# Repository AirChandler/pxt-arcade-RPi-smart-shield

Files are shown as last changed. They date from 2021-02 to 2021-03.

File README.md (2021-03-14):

# MakeCode Arcade smart shield firmware

Firmware for shields with screen/buttons that enable MakeCode Arcade.
The shield drives the screen (in particular it can bit-bang a 320x240 parallel
connection screen).

This firmware is just an example.
Shield manufactures can use it as a base for their own development.

More information on Arcade shield can be found at
in [the Arcade shield spec](https://github.com/microsoft/pxt-arcade-hardware-designs/tree/master/microbit-shield#smart-shield)
and in particular in the [PDF schematic](https://github.com/microsoft/pxt-arcade-hardware-designs/blob/master/microbit-shield/smart-shield-v0.0.0.pdf).

## Building

You will need a Unix-like environment to build the firmware.
On Windows, you can use Windows Subsystem for Linux or mingw32.

* install `arm-none-eabi-gcc` (we've been using `9-2019-q4-major`)
* install `openocd` (optional when using Black Magic Probe)
* install GNU Make
* run `make`; you should get a successful build

Upon first run of `make`, a `Makefile.user` file will be created.
You will want to adjust the settings in there - there are comments in there that should guide you through the process.

To deploy the firmware to a module you will need a debugger interface.
You have three options:
* [Black Magic Probe](https://github.com/blacksphere/blackmagic/wiki);
  you can also re-program other debuggers with BMP firmware
* a CMSIS-DAP debugger; we've been using 
  [Particle Debugger](https://store.particle.io/products/particle-debugger);
  make sure to disconnect micro:bit USB port from your computer when using this
* an ST-LINK/V2 or one of its clones - this is the default setting
You will want to set the right interface in `Makefile.user`.

## First deployment

Head to `main.c`, uncomment call to `show_test_screen()`.
Now deploy your program by running `make run` (or `make r` for short).
You'll likely need to have micro:bit connected to the shield
to close the power circuit.
You should see vertical stripes on the screen.

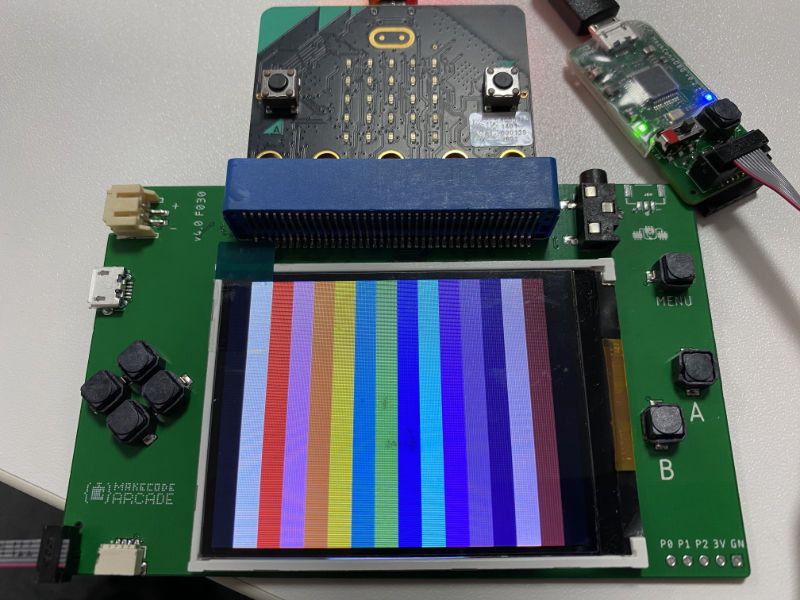
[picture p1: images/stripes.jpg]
Vertical stripes showing on the shield screen


If you don't:
* make sure the screen is hardware-configured as 8-bit parallel (and not 16-bit or SPI)
* make sure the screen is using pins `D[17:10]` for communication (`IM3-0` are `1001`);
  see Section 4. of ILI9341 datasheet
* make sure it's an ILI9341 screen; if not you may need to edit `ili9341.c` file

Once you have the screen running, comment out `show_test_screen()` and deploy again.
You now should be able to run Arcade games on the micro:bit.

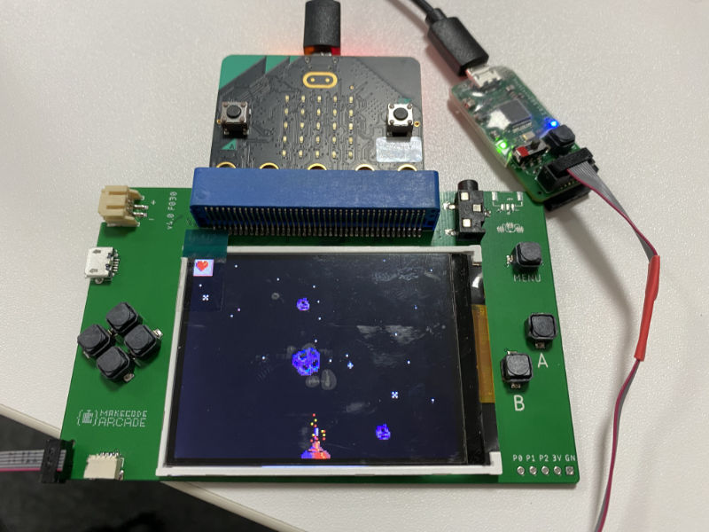
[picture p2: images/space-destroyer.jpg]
Space destroyer game showing on the shield screen


### Notable make targets

Other than the building/deployment targets, the following might be of note:

* `make gdb` - run GDB debugger
* `make clean` - clean (duh!)

## JACDAC Protol

Read more on jacdac protol implementation specification here:
https://microsoft.github.io/jacdac-docs/reference/protocol/

## Contributing

This project welcomes contributions and suggestions.  Most contributions require you to agree to a
Contributor License Agreement (CLA) declaring that you have the right to, and actually do, grant us
the rights to use your contribution. For details, visit https://cla.opensource.microsoft.com.

When you submit a pull request, a CLA bot will automatically determine whether you need to provide
a CLA and decorate the PR appropriately (e.g., status check, comment). Simply follow the instructions
provided by the bot. You will only need to do this once across all repos using our CLA.

This project has adopted the [Microsoft Open Source Code of Conduct](https://opensource.microsoft.com/codeofconduct/).
For more information see the [Code of Conduct FAQ](https://opensource.microsoft.com/codeofconduct/faq/) or
contact [opencode@microsoft.com](mailto:opencode@microsoft.com) with any additional questions or comments.

## Legal Notices

Microsoft, Windows, Microsoft Azure and/or other Microsoft products and services referenced in the documentation
may be either trademarks or registered trademarks of Microsoft in the United States and/or other countries.
The licenses for this project do not grant you rights to use any Microsoft names, logos, or trademarks.
Microsoft's general trademark guidelines can be found at http://go.microsoft.com/fwlink/?LinkID=254653.

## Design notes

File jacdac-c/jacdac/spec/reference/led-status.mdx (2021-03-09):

---
title: LED status
order: 4
---

# LED status

Jacdac modules typically have a status LED 
that is very useful to quickly troubleshoot them.
The sections below details the blinking patterns
and their associated states.

<StatusLEDAnimation status="connected" />

When connected, all modules on the Jacdac bus do a short synchronized blink (50us) every 500ms.

This is the happy state, everything is working and communicating properly.

<StatusLEDAnimation status="startup" />

On startup, the LED lights up at 100% for 270ms, then 5.9% for rest of 530ms, 
then goes into application that turns it on full for 200ms.

<StatusLEDAnimation status="identify" />

When you ask a device to identify itself, it will start a blinking sequence 
50ms every 150ms (50 on, 100 off) seven times (i.e. for 1 second).

<StatusLEDAnimation status="disconnected" />

When the device does not receive any Jacdac packet for some time, 
it enters the **disconnected** mode and blinks 5ms every 250ms.

* check that the cable is properly secured on your module
* check that the other modules are in connected mode as well

<StatusLEDAnimation status="panic" />

If the firmware crashes, it will enter **panic** mode
and do a fast blink 70ms on, 70ms off - 30 times (4.2 seconds) before a reboot.

<StatusLEDAnimation status="bootloader" />

Every 524ms it changes from 5.9% and 1.6% (i.e. 1 sec duty cycle)

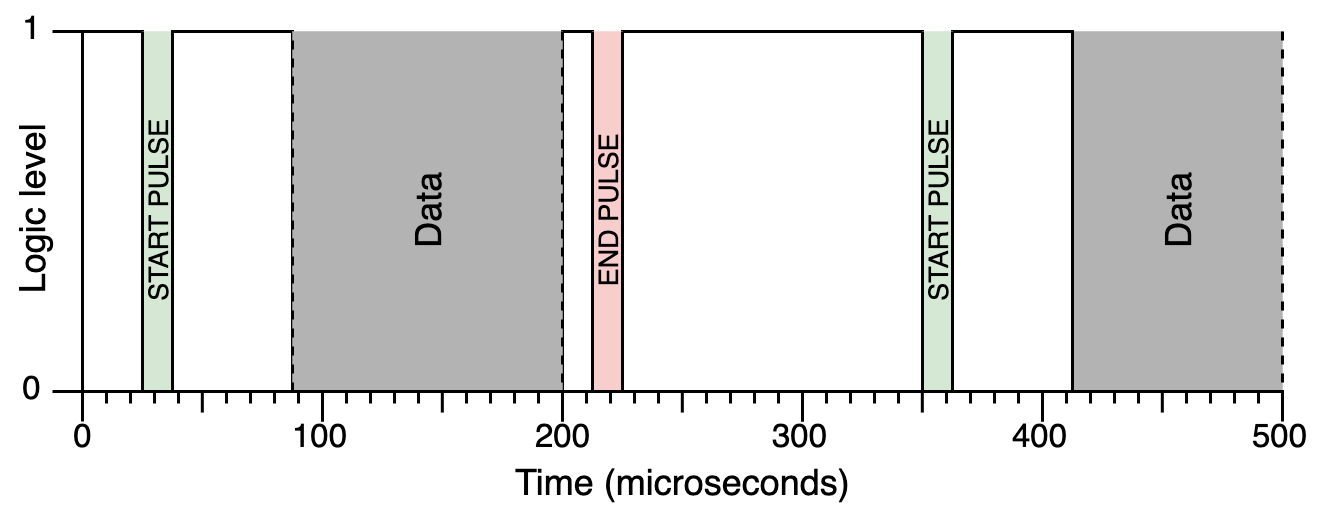
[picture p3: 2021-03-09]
jacdac-c/jacdac/spec/images/jacdac-activity.png

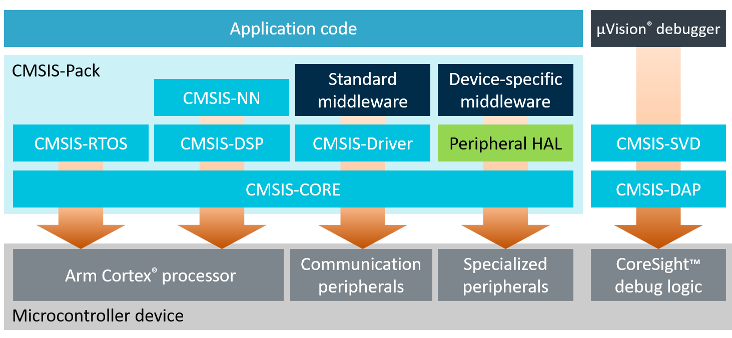
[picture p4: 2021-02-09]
cmsis_core/docs/General/html/Overview.png

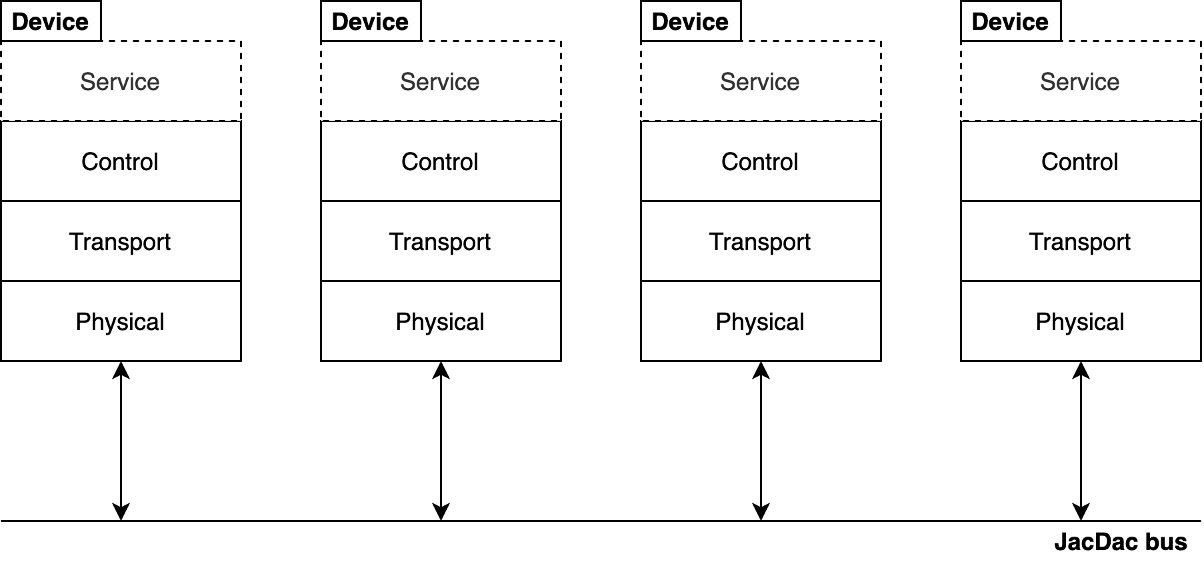
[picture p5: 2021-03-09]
jacdac-c/jacdac/spec/images/jacdac-stack.png

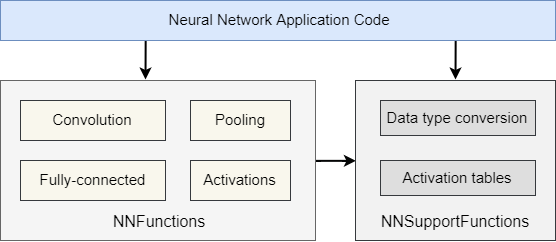
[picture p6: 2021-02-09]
cmsis_core/docs/NN/html/CMSIS-NN-OVERVIEW.PNG

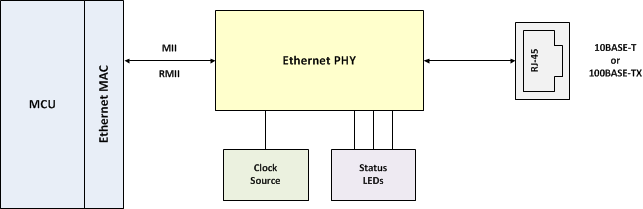
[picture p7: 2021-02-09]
cmsis_core/docs/Driver/html/EthernetSchematic.png

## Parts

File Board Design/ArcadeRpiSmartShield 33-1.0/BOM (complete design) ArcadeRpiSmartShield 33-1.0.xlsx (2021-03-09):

Comment | Description | Designator | Footprint | LibRef | Quantity | Supplier 1 | Supplier 2 | Supplier 3 | Supplier 4 | Supplier Currency 1 | Supplier Currency 2 | Supplier Currency 3 | Supplier Currency 4 | Supplier Order Qty 1 | Supplier Order Qty 2 | Supplier Order Qty 3 | Supplier Order Qty 4 | Supplier Part Number 1 | Supplier Part Number 2 | Supplier Part Number 3 | Supplier Part Number 4 | Supplier Stock 1 | Supplier Stock 2 | Supplier Stock 3 | Supplier Stock 4 | Supplier Subtotal 1 | Supplier Subtotal 2 | Supplier Subtotal 3 | Supplier Subtotal 4 | Supplier Subtotal per Board 1 | Supplier Subtotal per Board 2 | Supplier Subtotal per Board 3 | Supplier Subtotal per Board 4 | Supplier Unit Price 1 | Supplier Unit Price 2 | Supplier Unit Price 3 | Supplier Unit Price 4 | Manufacturer | Manufacturer Part Number
CL05B104KQ5NNNC | CAP CER 0.1UF 6.3V X7R 0402 | C1, C2, C3 | C0402_0.55MM - without outline | CL05B104KQ5NNNC | 3 | Digi-Key | Mouser |  |  | USD | USD |  |  | 3000 | 3000 |  |  | 1276-1511-1-ND | 187-CL05B104KQ5NNNC |  |  | 647878 | 0 |  |  | 17.16 | 21 |  |  | 0.01716 | 0.021 |  |  | 0.00572 | 0.007 |  |  | Samsung | CL05B104KQ5NNNC
SML-D12D | 1.6 x 0.8 x 0.55mm (0603) LED 605nm Orange | D1 | Rohm SML-D12 Orange - without outline | SML-D12D | 1 | Digi-Key |  |  |  | USD |  |  |  | 1000 |  |  |  | 511-1577-1-ND |  |  |  | 26976 |  |  |  | 59.78 |  |  |  | 0.05978 |  |  |  | 0.05978 |  |  |  | Rohm Semiconductor | SML-D12D8WT86
SML-D12P | 1.6 x 0.8 x 0.55mm (0603) LED 560nm Green | D2 | Rohm SML-D12 Green - without outline | SML-D12P | 1 | Digi-Key |  |  |  | USD |  |  |  | 1000 |  |  |  | 511-1579-1-ND |  |  |  | 49415 |  |  |  | 59.78 |  |  |  | 0.05978 |  |  |  | 0.05978 |  |  |  | Rohm Semiconductor | SML-D12P8WT86
SML-D12U | 1.6 x 0.8 x 0.55mm (0603) LED 620nm Red | D3 | Rohm SML-D12 Red - without outline | SML-D12U | 1 | Digi-Key | Farnell |  |  | USD | GBP |  |  | 1000 | 1000 |  |  | 511-1580-1-ND | 1685094 |  |  | 27915 | 4935 |  |  | 61.59 | 59.78 |  |  | 0.06159 | 0.05978 |  |  | 0.06159 | 0.05978 |  |  | Rohm Semiconductor | SML-D12U8WT86
Right Angle 1x40p 1.27 mm pitch edge connector for the micro:bit | "Right Angle" 1x40p 1.27mm Dongguan Yuliang BBC micro:bit edge connector | J1 | MIC127-140-A01 | MIC127-140-A01 | 1 |  |  |  |  |  |  |  |  |  |  |  |  |  |  |  |  |  |  |  |  |  |  |  |  |  |  |  |  |  |  |  |  | Dongguan Yuliang | MIC127-140-A01
HDR 2x3 0.100" | CONN HEADER VERT 6POS 2.54MM | J2 | PREC003DFAN-RC | PREC003DFAN-RC | 1 | Digi-Key |  |  |  | USD |  |  |  | 1000 |  |  |  | S2212EC-03-ND |  |  |  | 1243 |  |  |  | 88.7 |  |  |  | 0.0887 |  |  |  | 0.0887 |  |  |  | Sullins | PREC003DFAN-RC
SSW-120-01-G-D | 20 position 2 row (40 way) 0.1" TH socket | J4 | SAMTEC-SSW-120-01-G-D | SSW-120-01-G-D | 1 | Digi-Key | Farnell | Mouser | RSComponents | USD | GBP | USD | USD | 1000 | 1000 | 1000 | 1000 | SAM1208-20-ND | 1668397 | 200-SSW12001GD | 7655802 | 0 | 689 | 1740 | 0 | 3733.33 | 3530 | 4229 | 3982.08 | 3.73 | 3.53 | 4.23 | 3.98 | 3.73 | 3.53 | 4.23 | 3.98 | Samtec | SSW-120-01-G-D
HDR 8x1 0.098" | CONN HEADER VERT 8POS 2.5MM | J5 | B8B-XH-A(LF)(SN) | B8B-XH-A(LF)(SN) | 1 | Digi-Key | Farnell |  |  | USD | GBP |  |  | 1000 | 1000 |  |  | 455-2251-ND | 1516284 |  |  | 6017 | 11531 |  |  | 183.94 | 170.48 |  |  | 0.18394 | 0.17048 |  |  | 0.18394 | 0.17048 |  |  | JST | B8B-XH-A(LF)(SN)
RC0402FR-071KL | RES SMD 1K OHM 1% 1/16W 0402 | R1, R3, R4, R12 | R0402 - Without outline | RC0402FR-071KL | 4 | Digi-Key | Mouser | Farnell |  | USD | USD | GBP |  |  | 4000 | 4000 |  | 311-1.00KLRDKR-ND | 603-RC0402FR-071KL | 2132441 |  | 28494836 | 15980796 | 0 |  |  | 9.92 | 16 |  |  | 0.00992 | 0.016 |  |  | 0.00248 | 0.004 |  | Yageo | RC0402FR-071KL
RC0402FR-07100KL | RES SMD 100K OHM 1% 1/16W 0402 | R2, R5, R6, R7, R8, R9, R10, R11 | R0402 - Without outline | RC0402FR-07100KL | 8 | Digi-Key | Mouser | Farnell |  | USD | USD | GBP |  |  | 8000 | 8000 |  | 311-100KLRCT-ND | 603-RC0402FR-07100KL | 2131798 |  | 18044819 | 2925308 | 6041 |  |  | 16.4 | 32 |  |  | 0.0164 | 0.032 |  |  | 0.00205 | 0.004 |  | Yageo | RC0402FR-07100KL
STM32F030C8T6 | MCU 32-bit STM32F ARM Cortex M0 RISC 64KB Flash 2.5V/3.3V 48-Pin LQFP Tray | U1 | 48-LQFP (7x7) | STM32F030C8T6 | 1 | Digi-Key | Avnet |  |  | USD | USD |  |  | 1000 | 1000 |  |  | 497-14043-ND | 39X0182 |  |  | 0 | 325 |  |  | 1160 | 1303.4 |  |  | 1.16 | 1.3 |  |  | 1.16 | 1.3 |  |  | STMicroelectronics | STM32F030C8T6

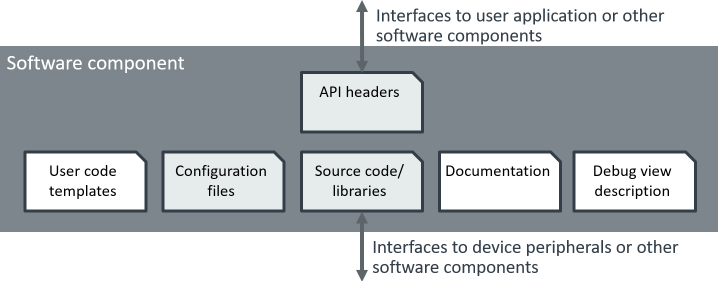
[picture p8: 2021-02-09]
cmsis_core/docs/Pack/html/software_component.png

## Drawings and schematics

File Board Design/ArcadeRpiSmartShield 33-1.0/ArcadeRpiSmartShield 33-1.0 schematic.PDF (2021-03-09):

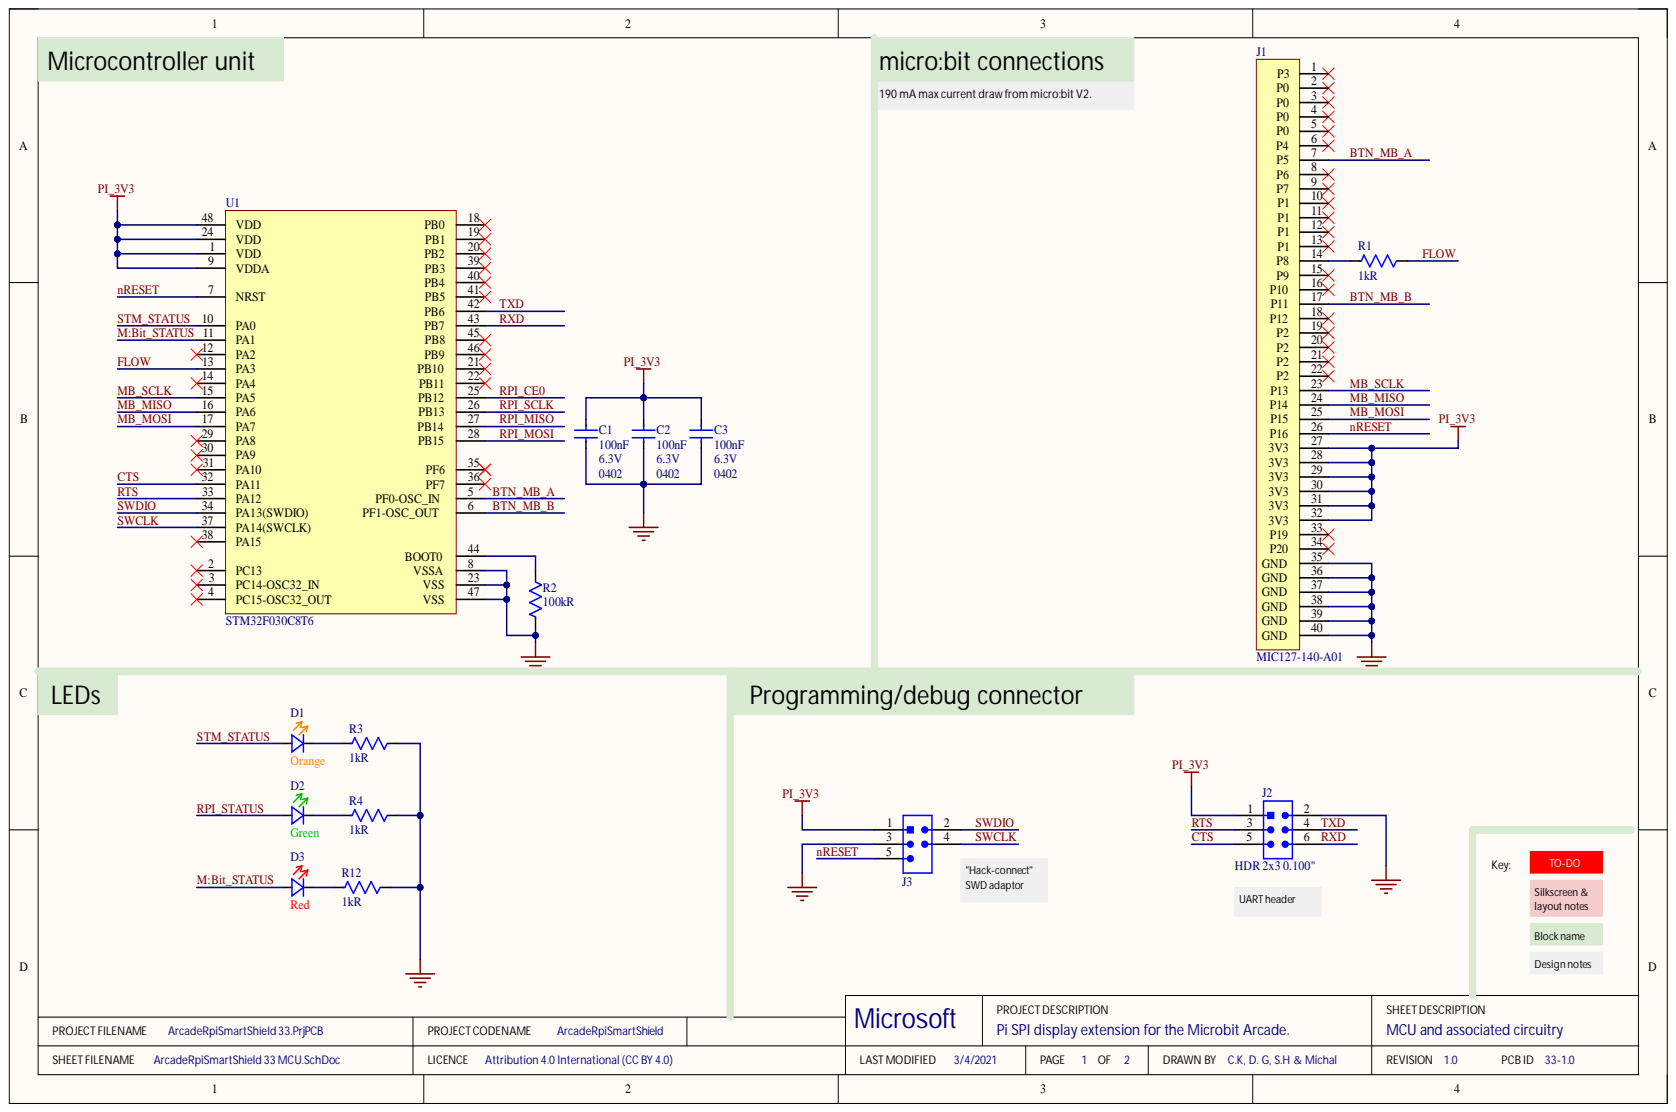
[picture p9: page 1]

2 4 | 1 9
1 | 2 0
9 | 3 9

2 3

Programming/debug connector nRESET

PROJE
Pi SPI display extension for the Microbit

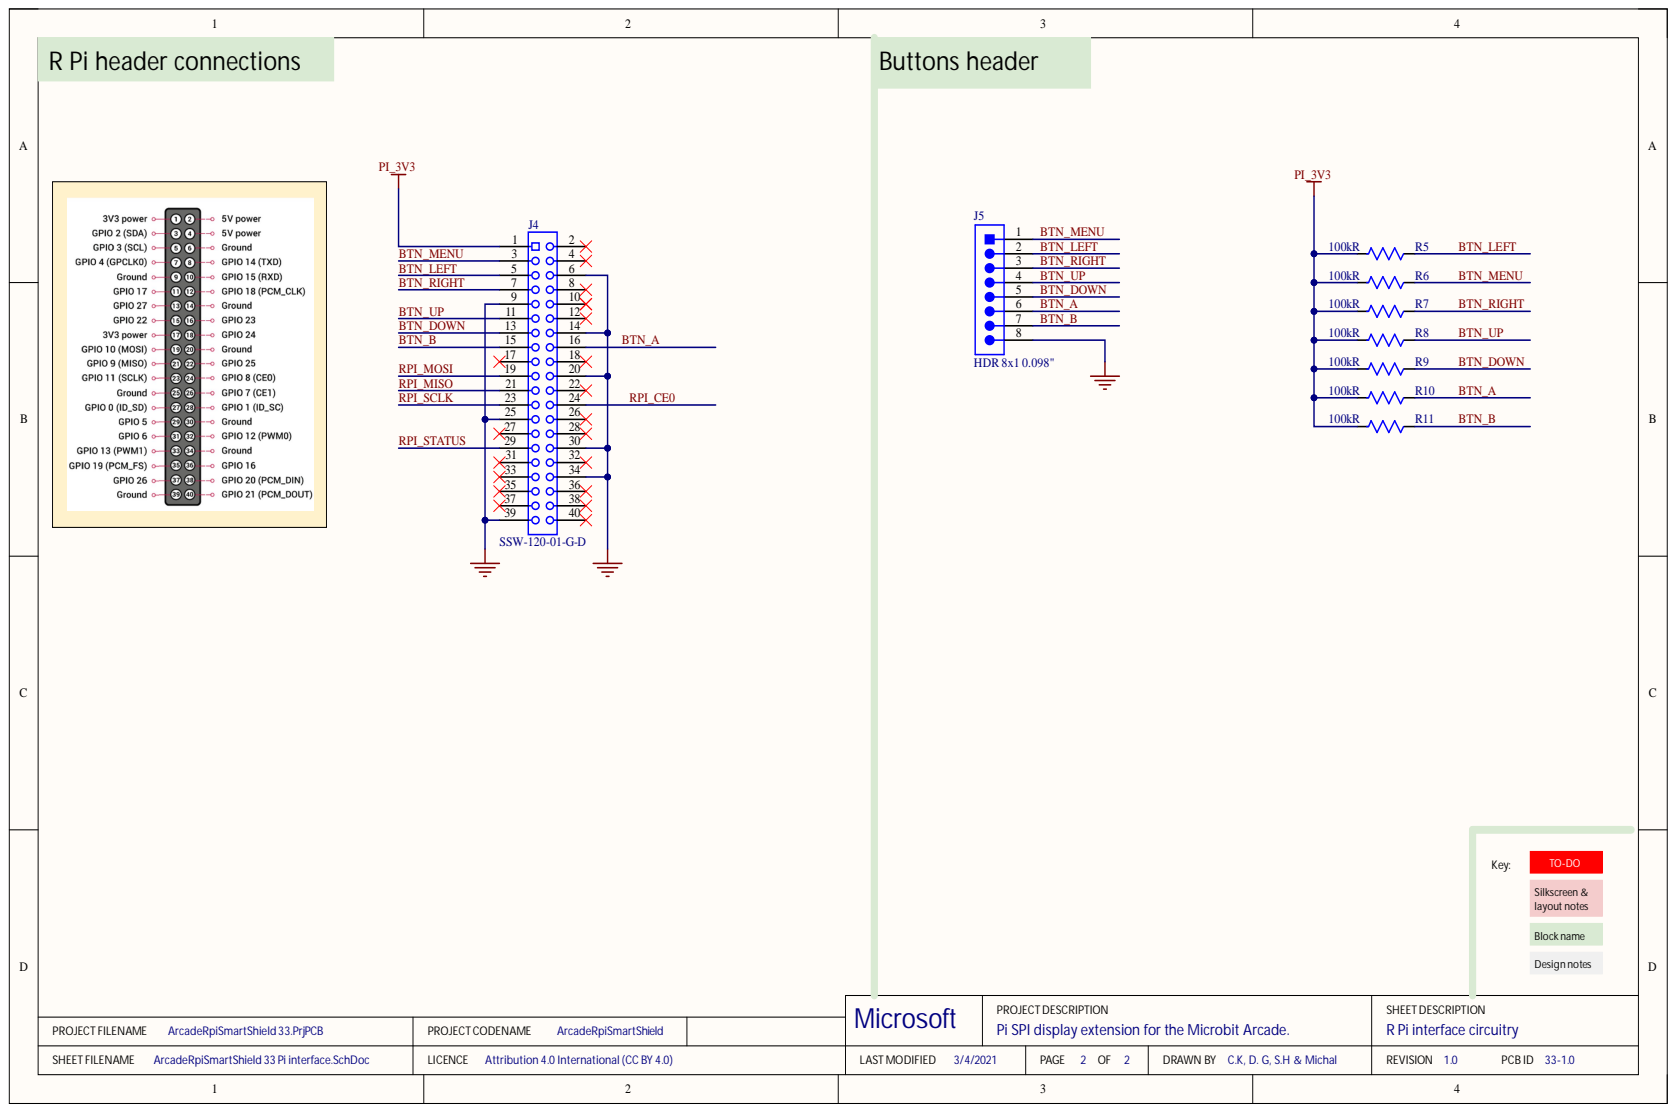
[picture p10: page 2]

PROJE
Pi SPI display extension for the Microbit

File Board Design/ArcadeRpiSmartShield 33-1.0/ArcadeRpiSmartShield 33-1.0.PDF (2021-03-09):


2 4 | 1 9
1 | 2 0
9 | 3 9

2 3

Programming/debug connector nRESET

PROJE
Pi SPI display extension for the Microbit


PROJE
Pi SPI display extension for the Microbit

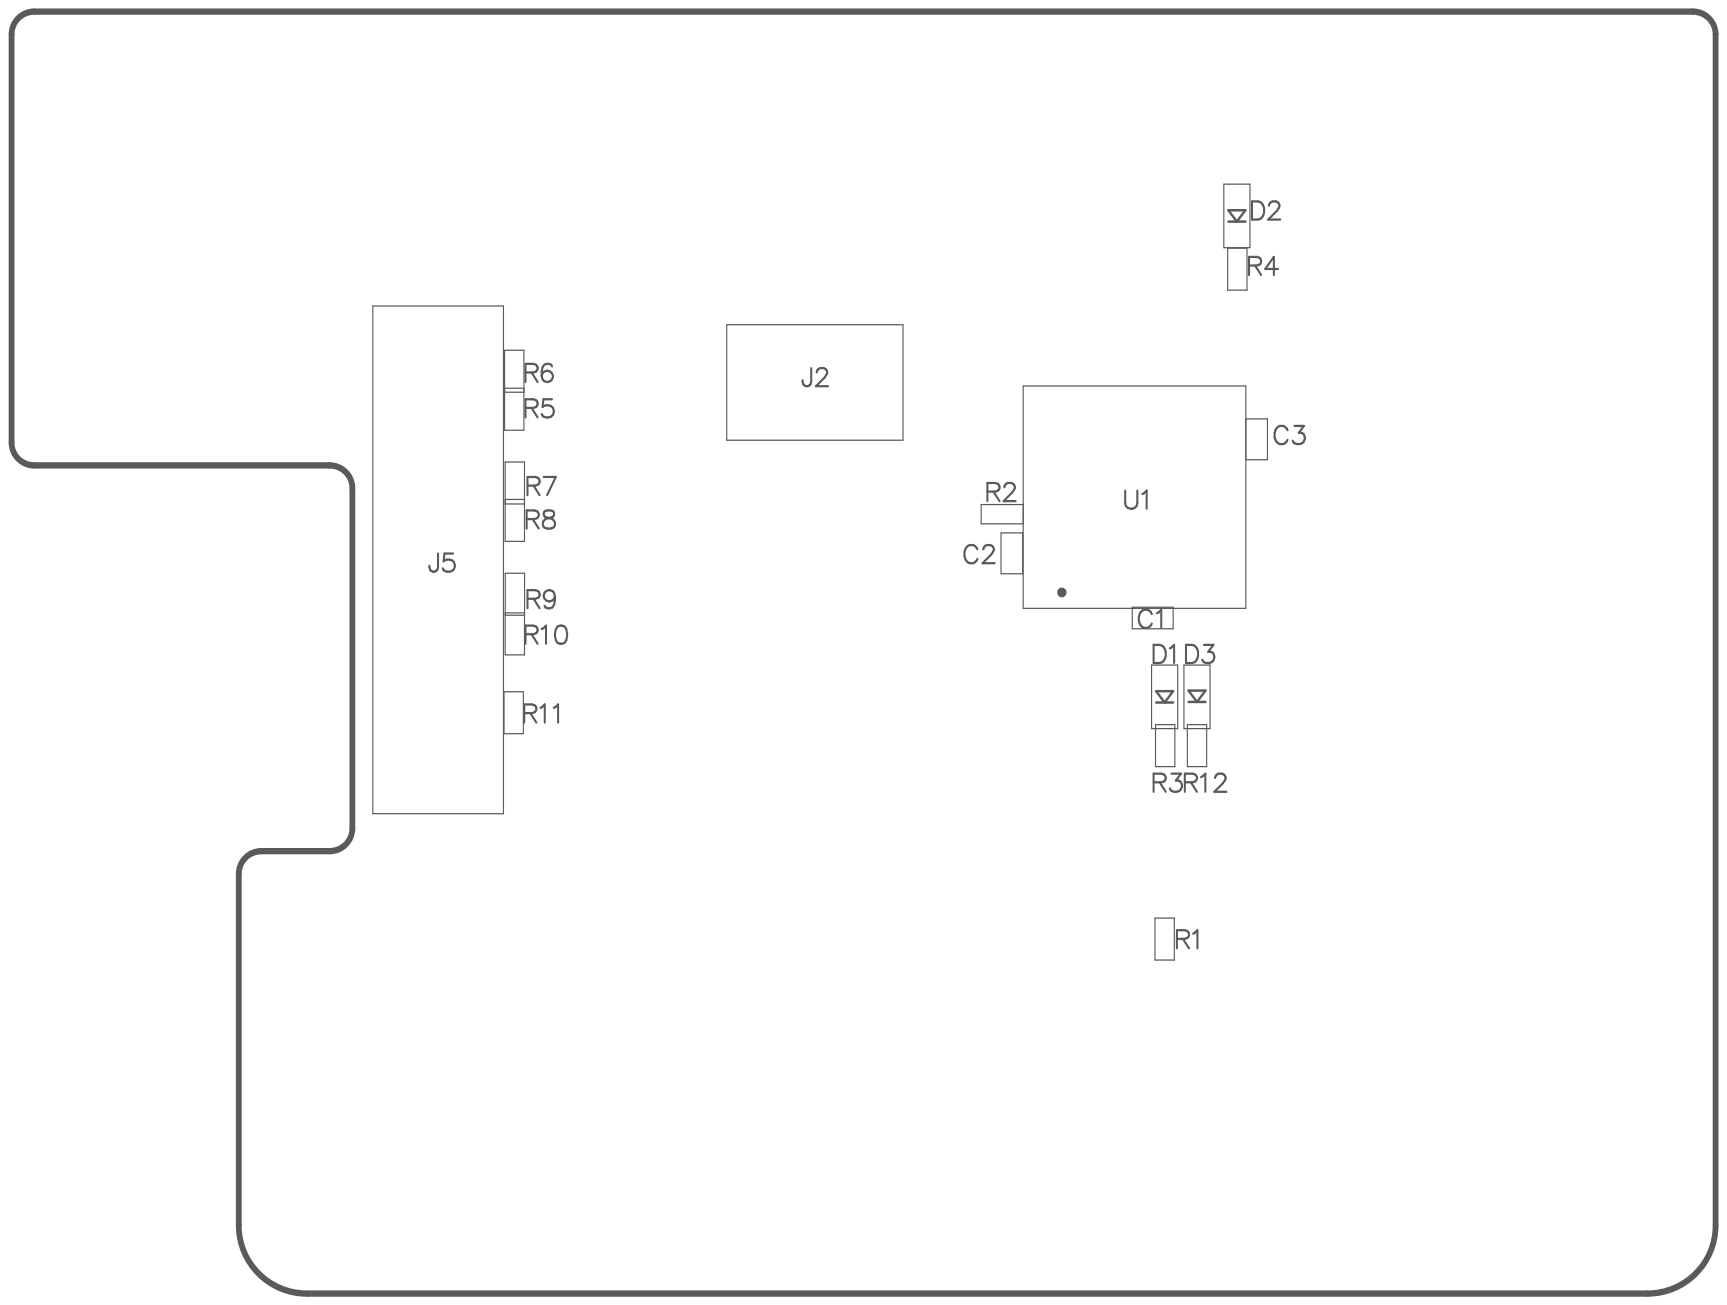
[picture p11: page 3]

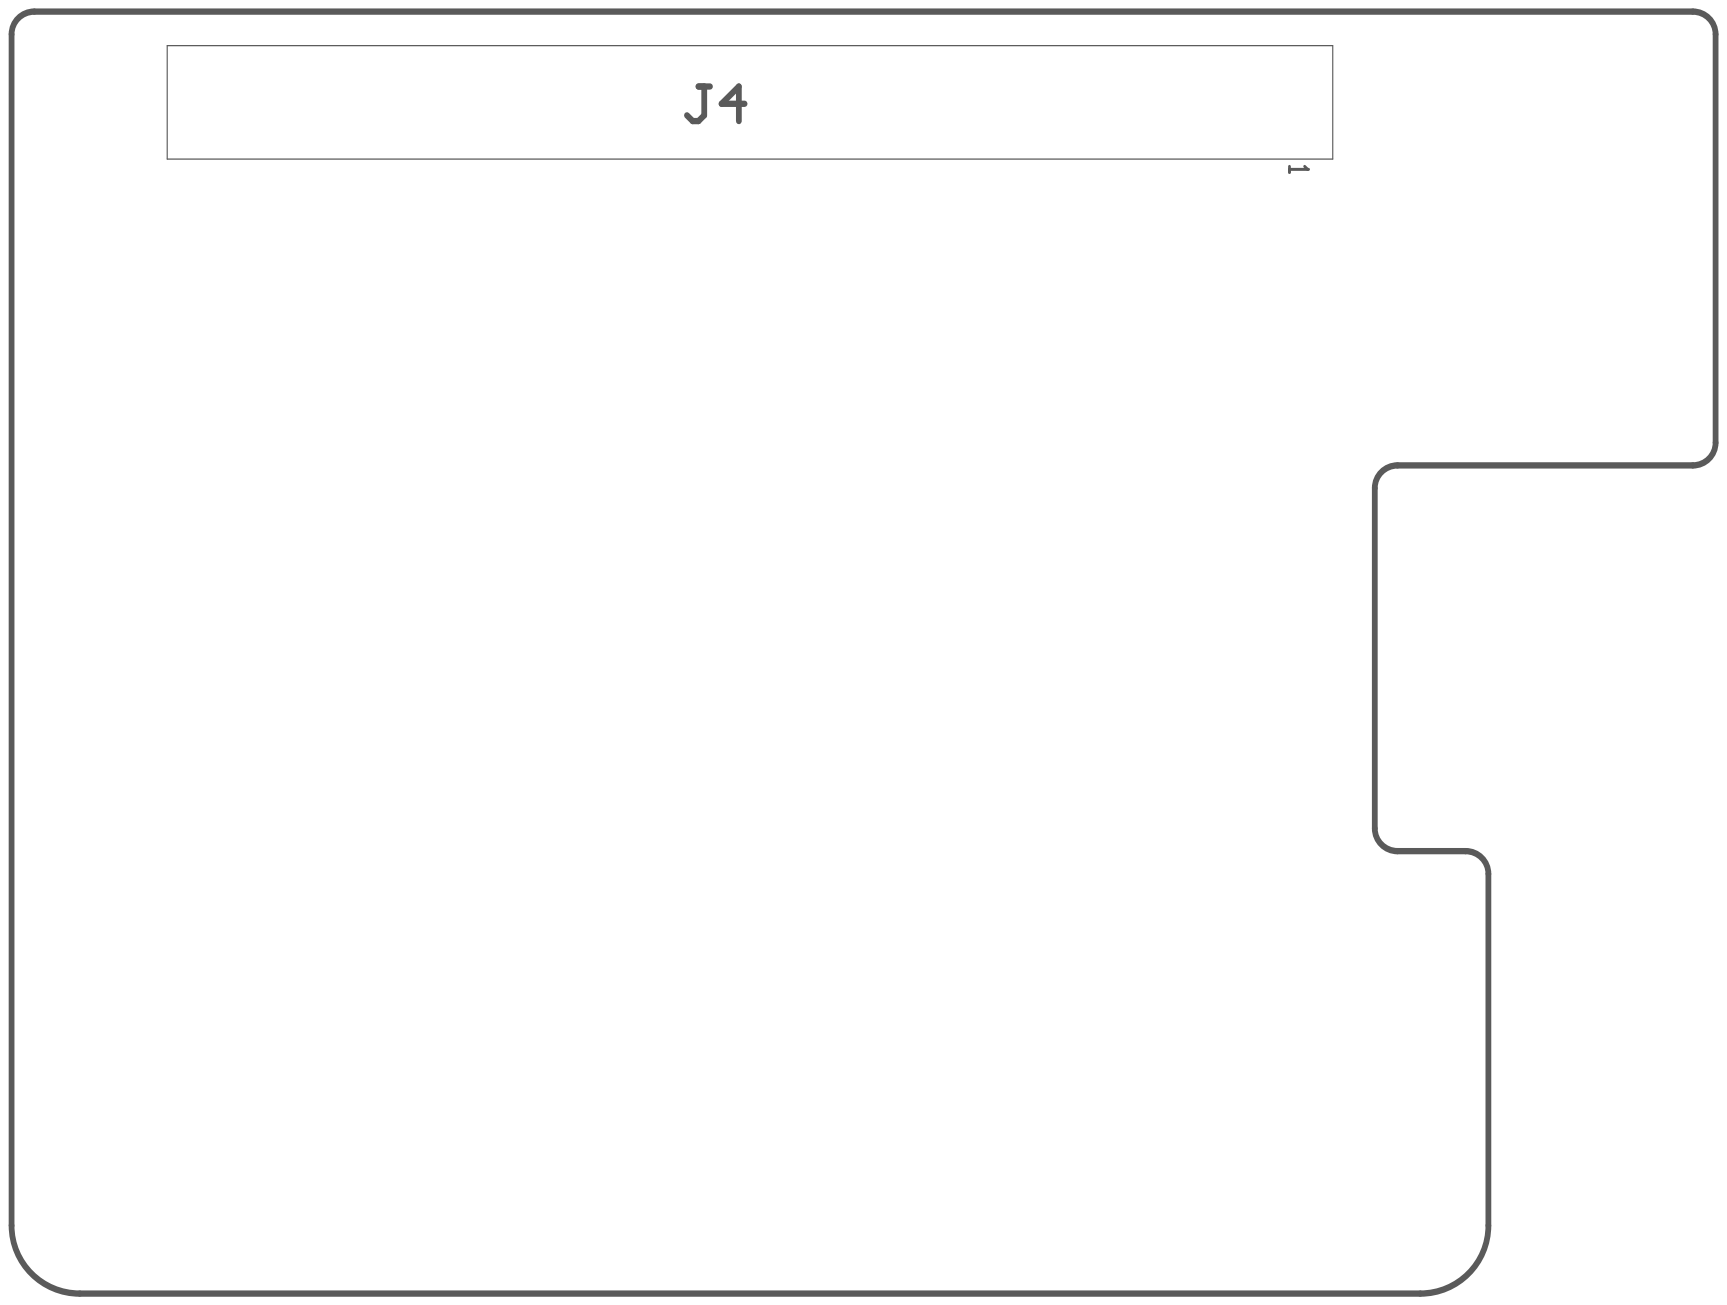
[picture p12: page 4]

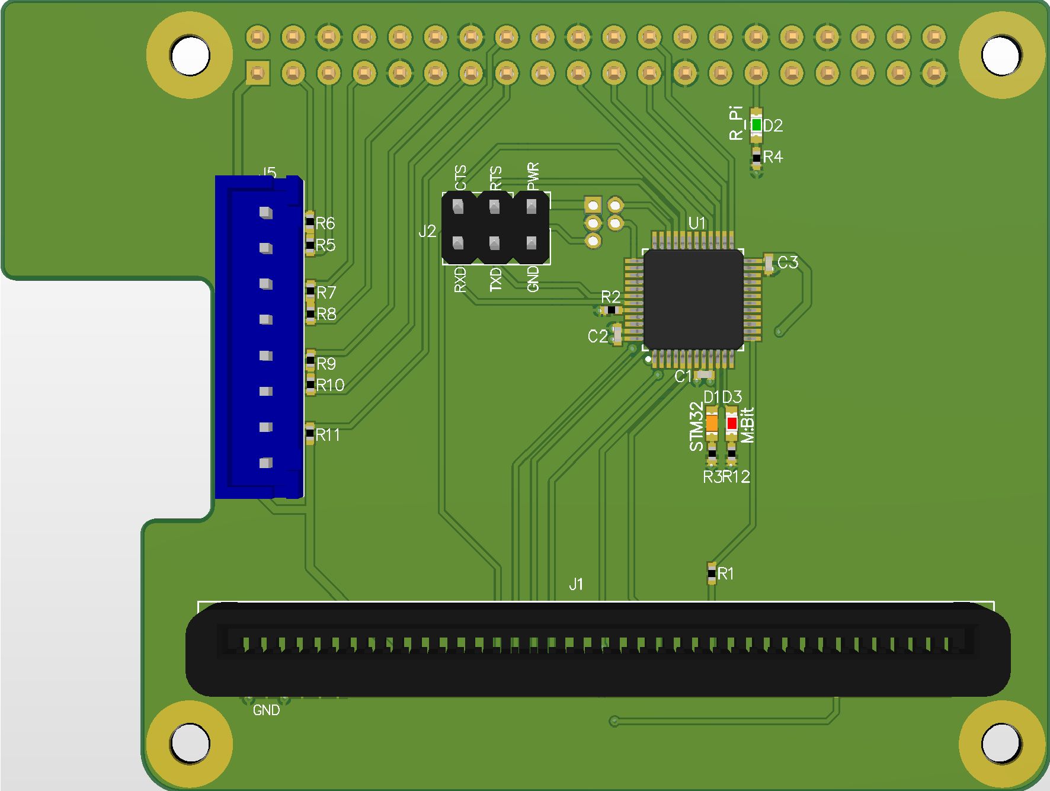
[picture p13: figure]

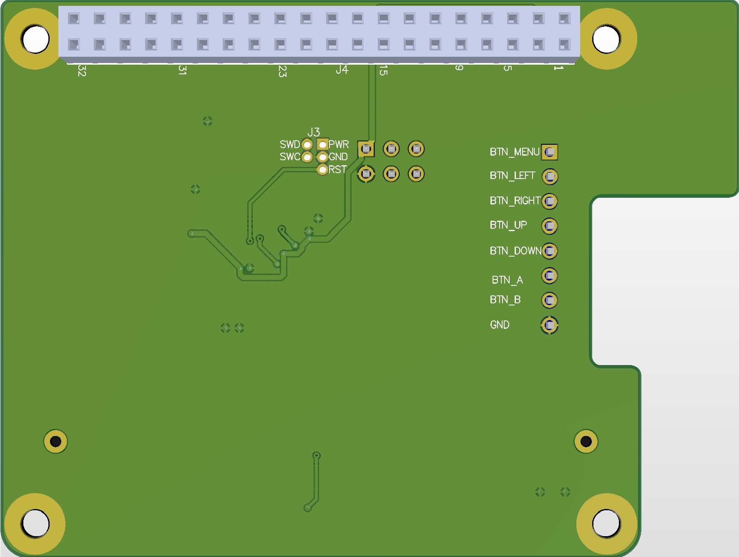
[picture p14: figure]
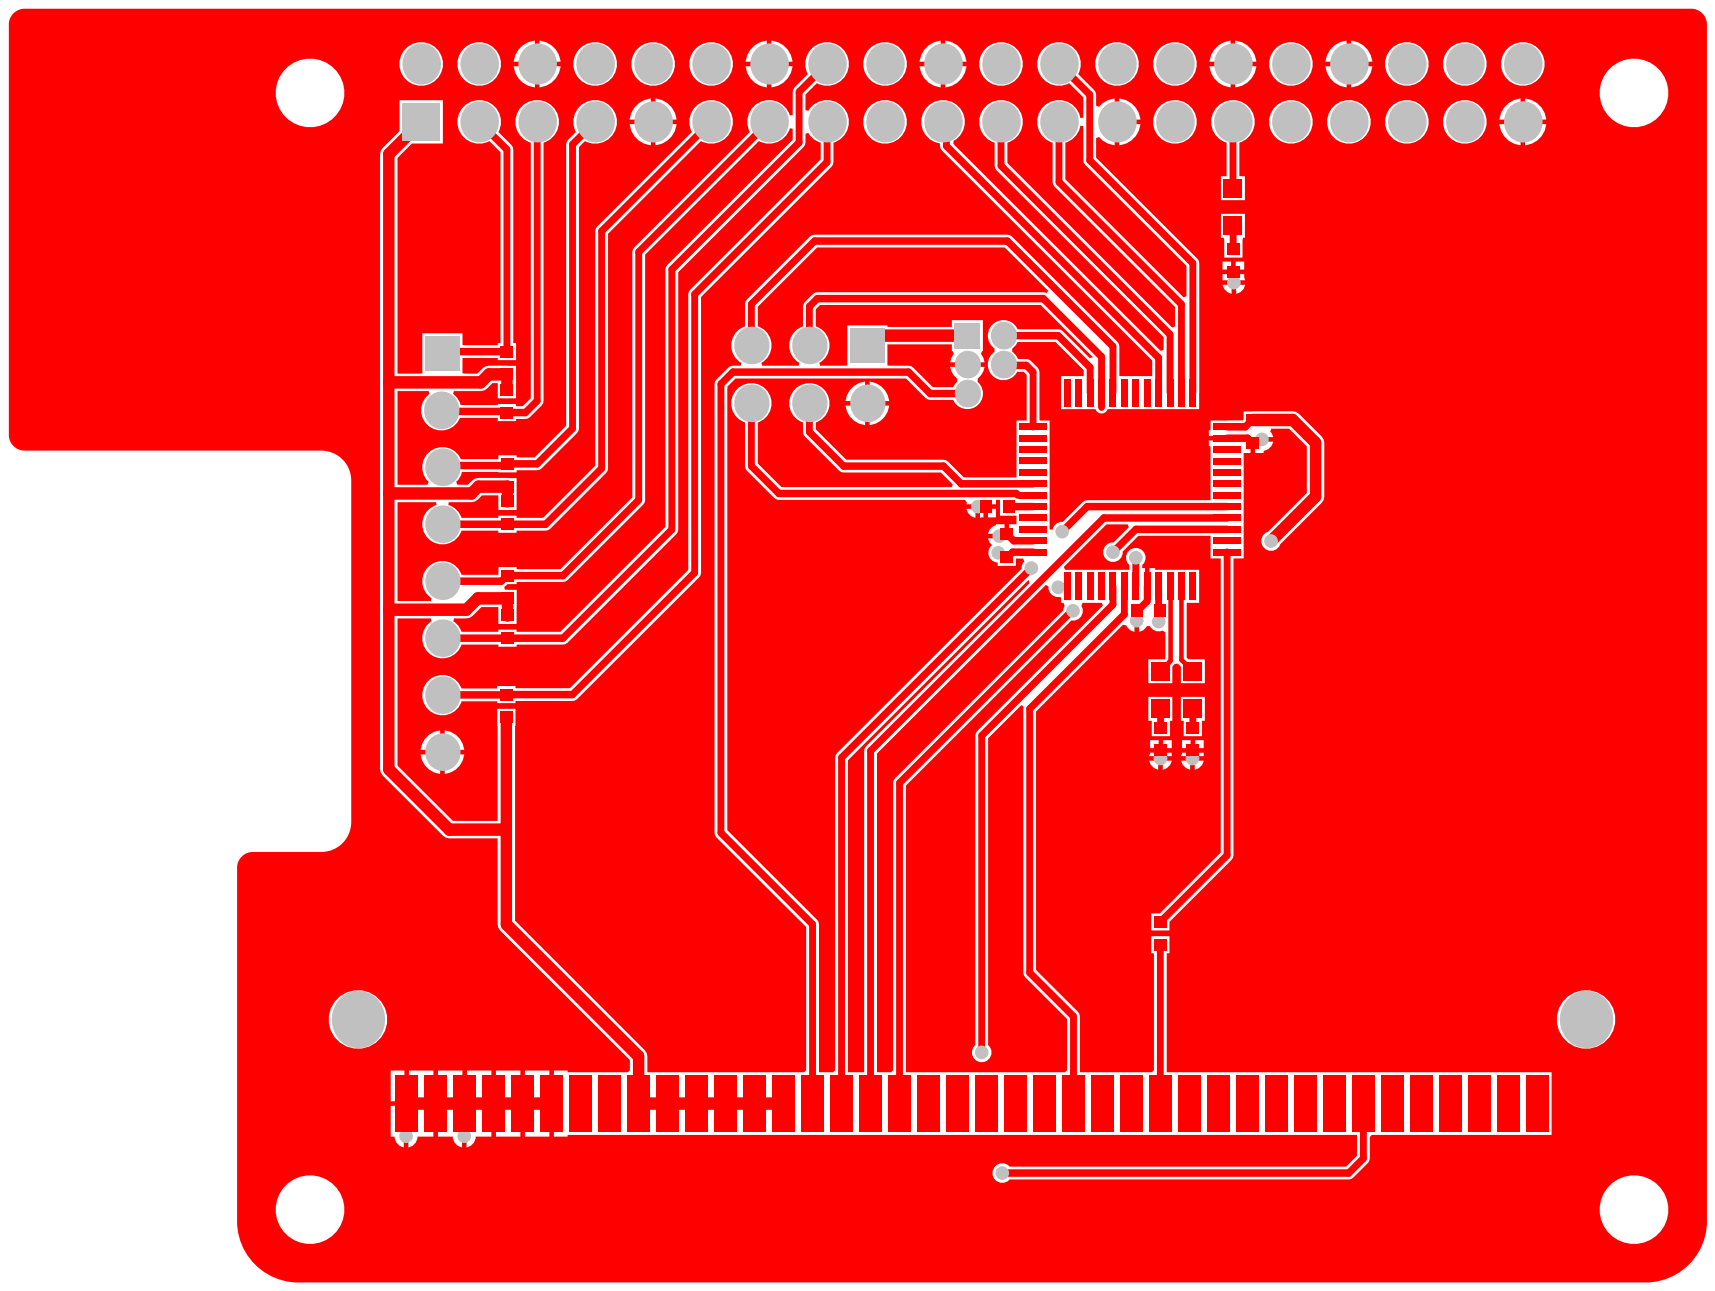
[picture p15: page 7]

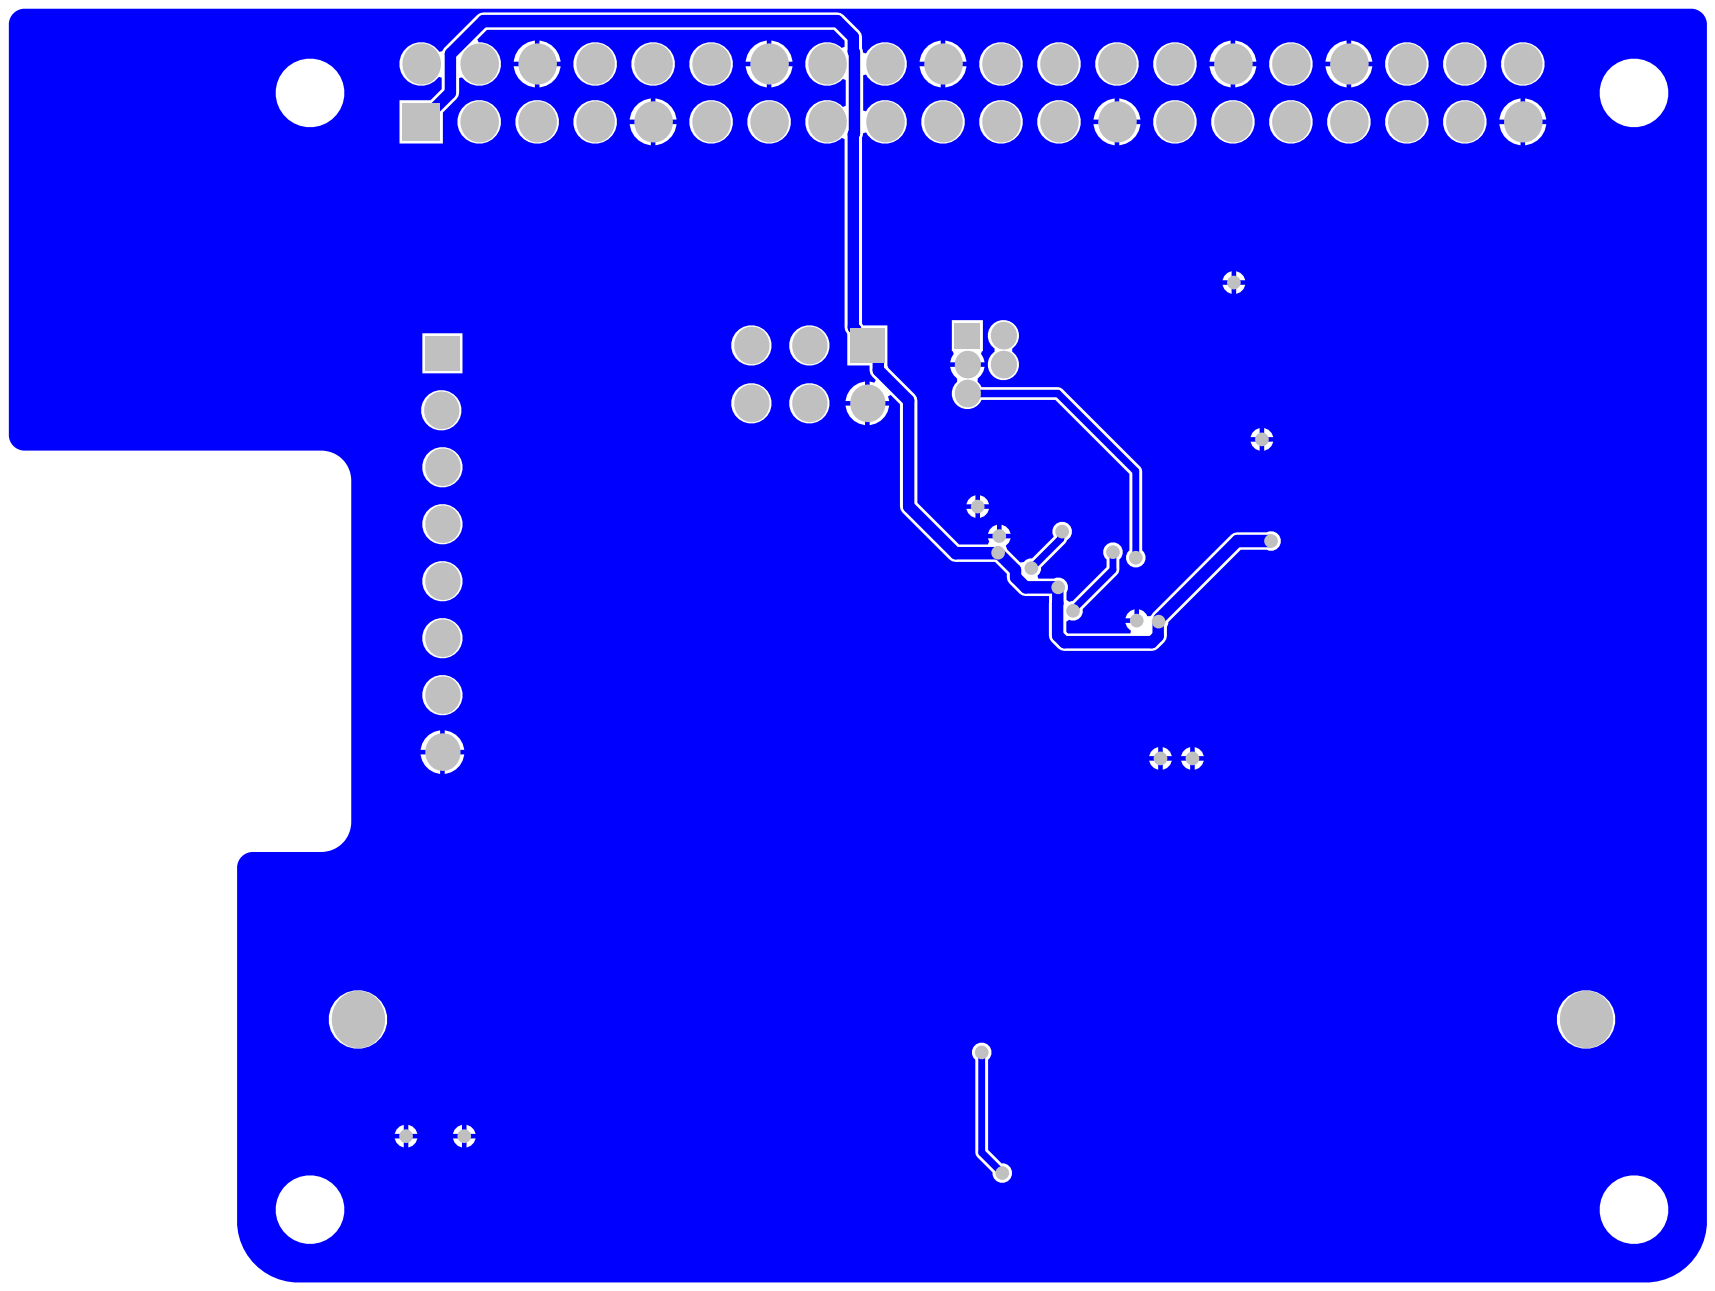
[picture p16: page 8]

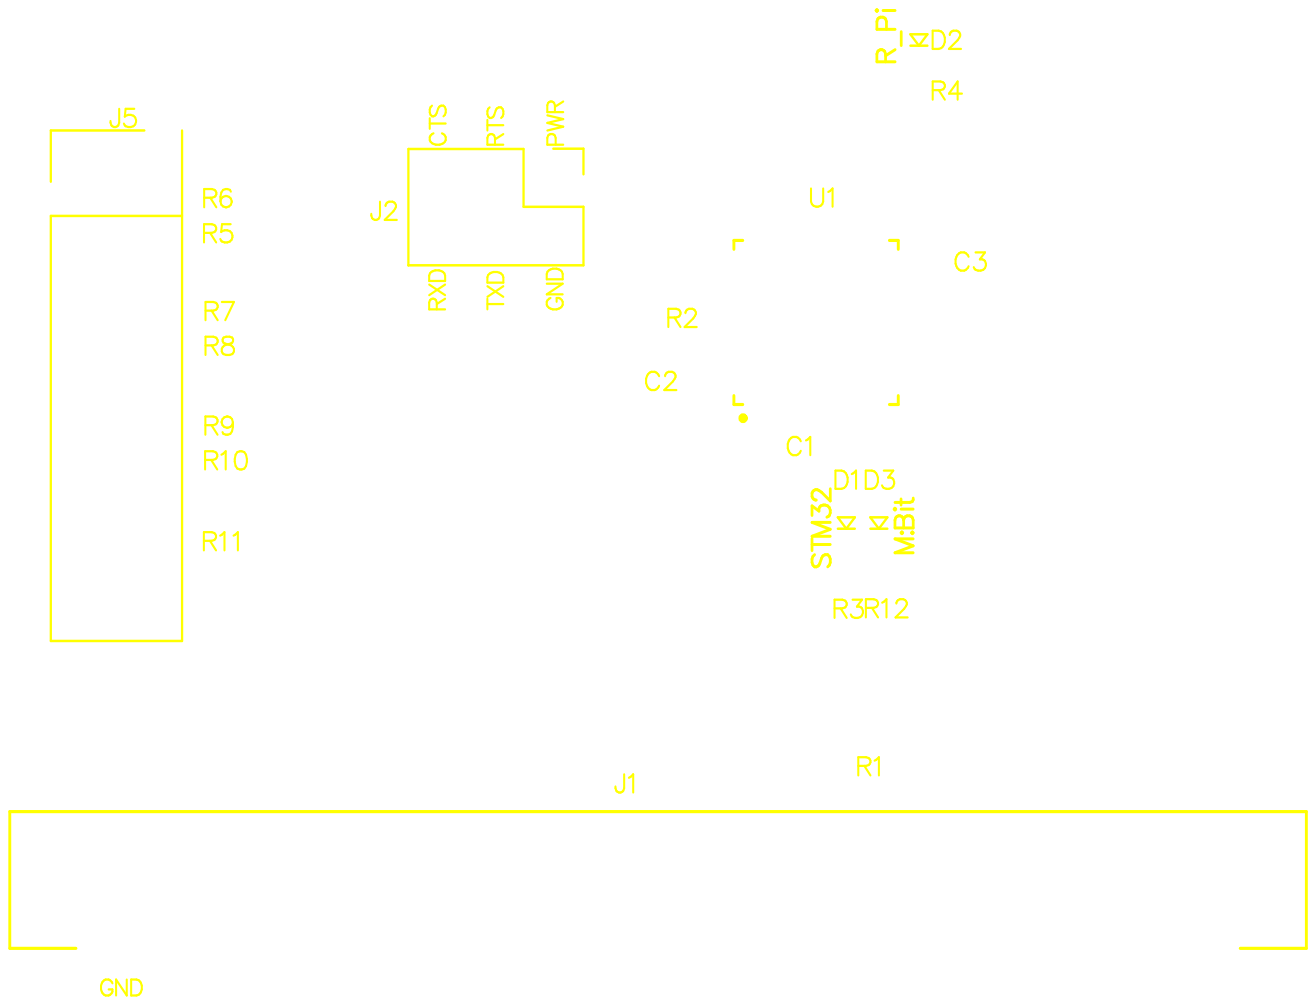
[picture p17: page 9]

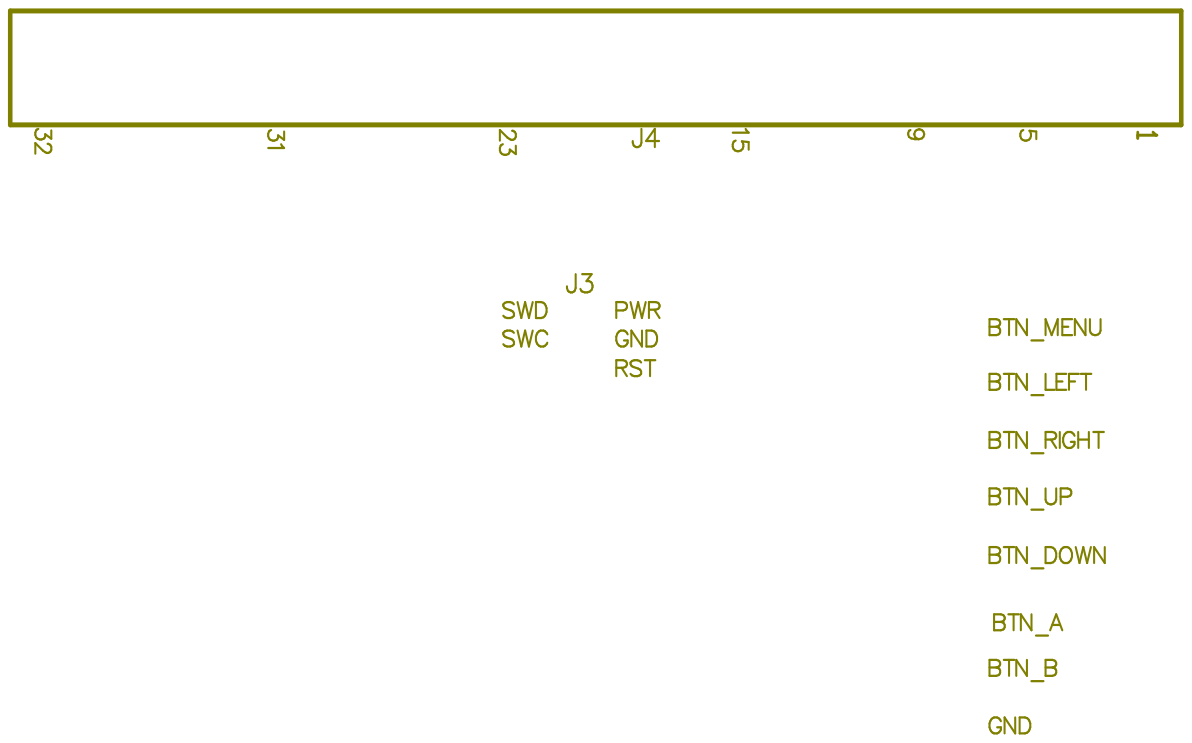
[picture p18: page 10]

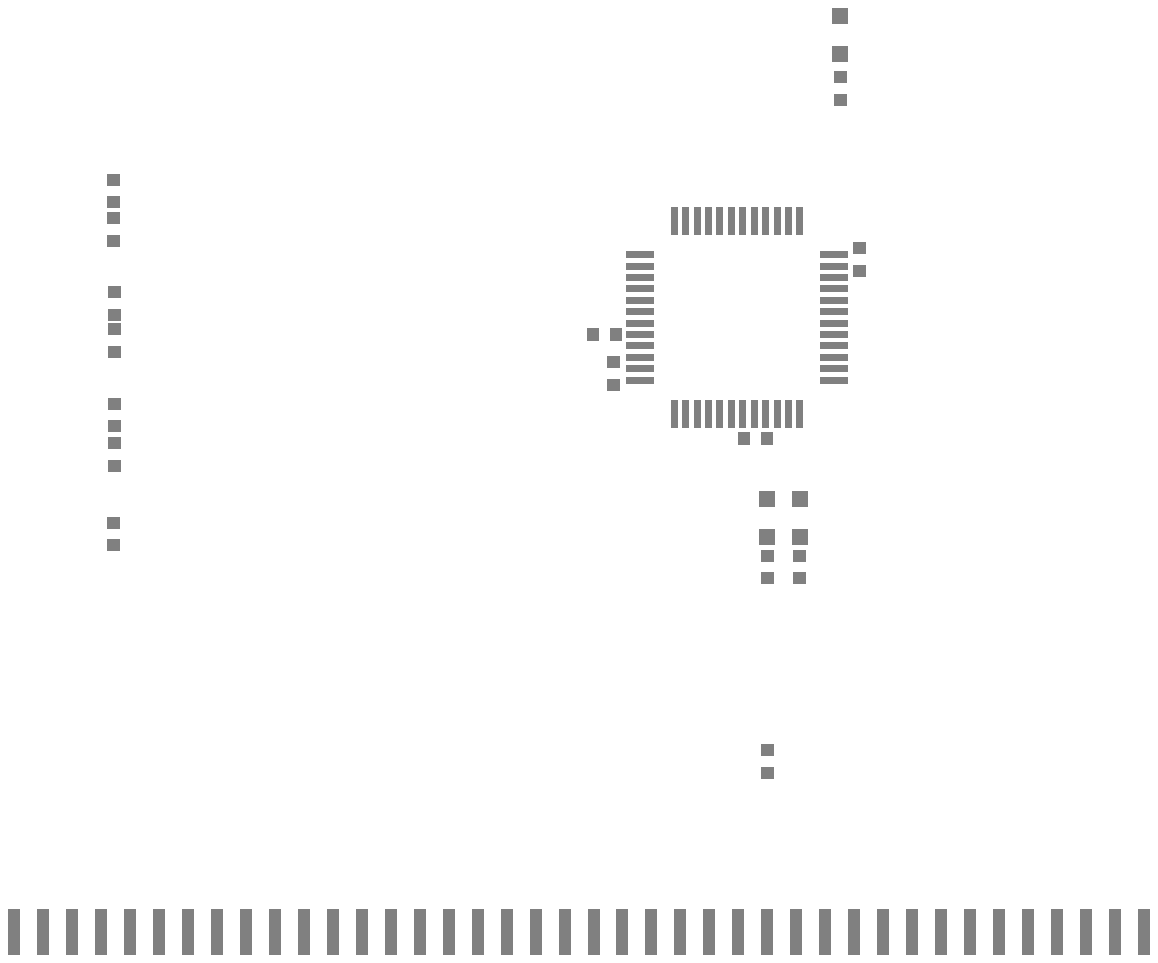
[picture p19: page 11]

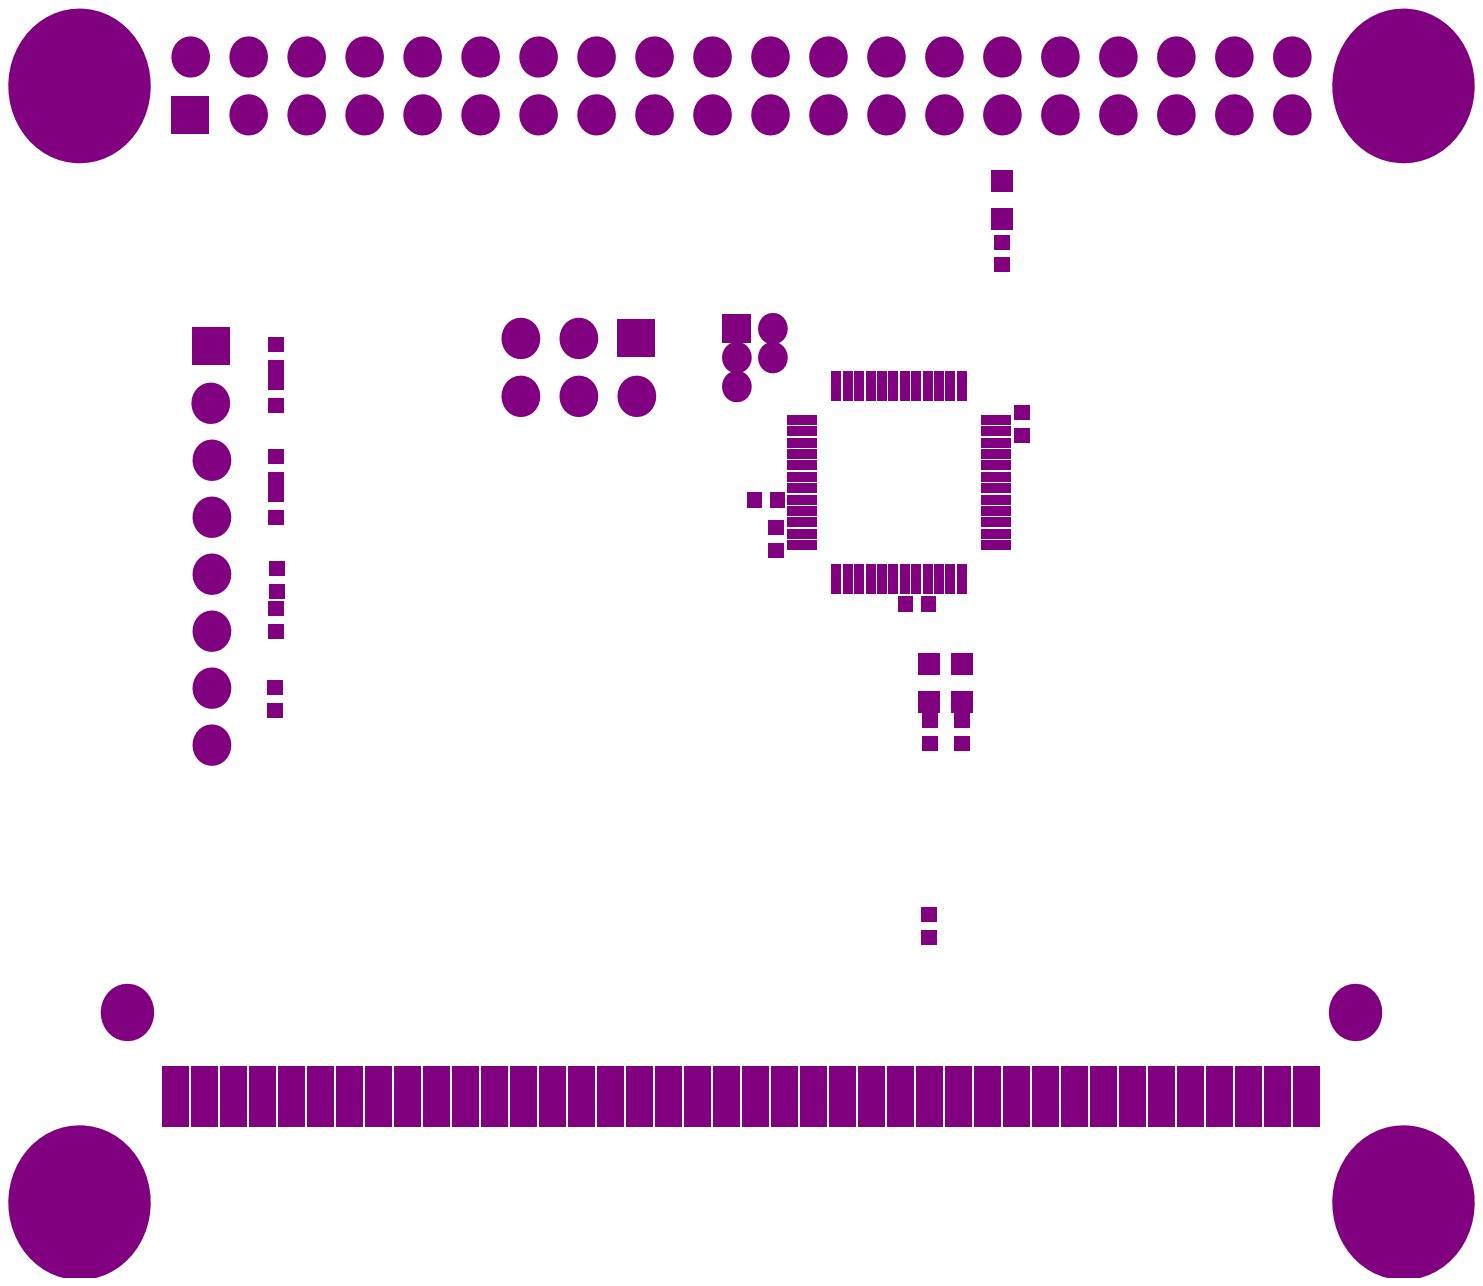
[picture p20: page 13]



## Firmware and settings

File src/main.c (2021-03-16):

// Copyright (c) Microsoft Corporation.
// Licensed under the MIT license.

#include "jdsimple.h"
#include "jdspi.h"
#include "rpi_flow.h"


void led_init() {
    pin_setup_output(PIN_LOG0);
    pin_setup_output(PIN_LOG1);
    pin_setup_output(PIN_LED);
}

void set_log_pin(int v) {
    pin_set(PIN_LOG0, v);
}

void set_log_pin2(int v) {
    pin_set(PIN_LOG1, v);
}

void pulse_log_pin() {
    set_log_pin(1);
    set_log_pin(0);
}

void pulse_log_pin2() {
    set_log_pin2(1);
    set_log_pin2(0);
}

void led_toggle() {
    pin_toggle(PIN_LED);
}

void led_set(int state) {
    pin_set(PIN_LED, state);
}

// uint8_t crcBuf[1024];

void tick() {
    // pulse_log_pin();
    tim_set_timer(10000, tick);
}

void screen_stripes(void);

void show_test_screen(void) {
  screen_set_backlight(255);
    screen_stripes();
    while(1);
}

int main(void) {

    jdspi_early_init();
    led_init();
    tim_init();
    adc_init_random();
    rpiHandler();
    while(1){
        //poll
    }
    /*
    // dspi_init();
    tick();
    jdspi_init();

    // show_test_screen();

    uint64_t lastBlink = tim_get_micros();
    while (1) {
        if (tim_get_micros() - lastBlink > 300000) {
            lastBlink = tim_get_micros();
            led_toggle();
        }
        jdspi_process();
    }*/
}

void panic(void) {
    DMESG("PANIC!");
    target_disable_irq();
    while (1) {
        led_toggle();
        wait_us(100000);
    }
}

void jd_panic() {
    panic();
}

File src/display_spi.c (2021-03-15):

// Copyright (c) Microsoft Corporation.
// Licensed under the MIT license.

#include "jdsimple.h"

#ifdef SPI2

#define SPI_IDX 2

#if SPI_IDX == 1
#define SPIx SPI1
#define IRQn SPI1_IRQn
#define IRQHandler SPI1_IRQHandler
#define LL_DMAMUX_REQ_SPIx_RX LL_DMAMUX_REQ_SPI1_RX
#define LL_DMAMUX_REQ_SPIx_TX LL_DMAMUX_REQ_SPI1_TX
#elif SPI_IDX == 2
#define SPIx SPI2
#define IRQn SPI2_IRQn
#define IRQHandler SPI2_IRQHandler
#define LL_DMAMUX_REQ_SPIx_RX LL_DMAMUX_REQ_SPI2_RX
#define LL_DMAMUX_REQ_SPIx_TX LL_DMAMUX_REQ_SPI2_TX
#else
#error "bad SPI"
#endif

#if SPI_IDX == 1
#define PIN_PORT GPIOA
#define PIN_SCK LL_GPIO_PIN_5
#define PIN_MOSI LL_GPIO_PIN_7
#define PIN_AF LL_GPIO_AF_0
#define SPI_CLK_ENABLE __HAL_RCC_SPI1_CLK_ENABLE
#elif SPI_IDX == 2
#define PIN_PORT GPIOB
#define SPI_CLK_ENABLE __HAL_RCC_SPI2_CLK_ENABLE
#ifdef STM32G0
#define PIN_SCK LL_GPIO_PIN_8
#define PIN_MOSI LL_GPIO_PIN_7
#define PIN_AF LL_GPIO_AF_1
#else
#define PIN_SCK LL_GPIO_PIN_13
#define PIN_MOSI LL_GPIO_PIN_15
#define PIN_AF LL_GPIO_AF_0
#endif
#else
#error "bad spi"
#endif

#ifdef STM32G0
#define DMA_CH LL_DMA_CHANNEL_1
#define DMA_IRQn DMA1_Channel1_IRQn
#define DMA_Handler DMA1_Channel1_IRQHandler
#define DMA_ClearFlag LL_DMA_ClearFlag_GI1
#else

#if SPI_IDX == 1
#define DMA_CH LL_DMA_CHANNEL_3
#define DMA_IRQn DMA1_Channel2_3_IRQn
#define DMA_Handler DMA1_Channel2_3_IRQHandler
#define DMA_ClearFlag LL_DMA_ClearFlag_GI3
#elif SPI_IDX == 2
#define DMA_CH LL_DMA_CHANNEL_5
#define DMA_IRQn DMA1_Channel4_5_IRQn
#define DMA_Handler DMA1_Channel4_5_IRQHandler
#define DMA_ClearFlag LL_DMA_ClearFlag_GI5
#else
#error "bad spi"
#endif

#endif

void dspi_init() {
    SPI_CLK_ENABLE();
    __HAL_RCC_DMA1_CLK_ENABLE();

    LL_GPIO_InitTypeDef GPIO_InitStruct = {0};

    GPIO_InitStruct.Pin = PIN_SCK | PIN_MOSI;
    GPIO_InitStruct.Mode = LL_GPIO_MODE_ALTERNATE;
    GPIO_InitStruct.Speed = LL_GPIO_SPEED_FREQ_HIGH;
    GPIO_InitStruct.OutputType = LL_GPIO_OUTPUT_PUSHPULL;
    GPIO_InitStruct.Pull = LL_GPIO_PULL_DOWN;
    GPIO_InitStruct.Alternate = PIN_AF;
    LL_GPIO_Init(PIN_PORT, &GPIO_InitStruct);

    SPIx->CR1 = LL_SPI_HALF_DUPLEX_TX | LL_SPI_MODE_MASTER | LL_SPI_NSS_SOFT |
                LL_SPI_BAUDRATEPRESCALER_DIV2;
    SPIx->CR2 = LL_SPI_DATAWIDTH_8BIT | LL_SPI_RX_FIFO_TH_QUARTER;

    // LL_SPI_EnableIT_TXE(SPIx);
    // LL_SPI_EnableIT_RXNE(SPIx);
    LL_SPI_EnableIT_ERR(SPIx);

#ifdef STM32G0
    LL_DMA_SetPeriphRequest(DMA1, DMA_CH, LL_DMAMUX_REQ_SPIx_TX);
#endif
    LL_DMA_ConfigTransfer(DMA1, DMA_CH,
                          LL_DMA_DIRECTION_MEMORY_TO_PERIPH | //
                              LL_DMA_PRIORITY_LOW |           //
                              LL_DMA_MODE_NORMAL |            //
                              LL_DMA_PERIPH_NOINCREMENT |     //
                              LL_DMA_MEMORY_INCREMENT |       //
                              LL_DMA_PDATAALIGN_BYTE |        //
                              LL_DMA_MDATAALIGN_BYTE);

    /* Enable DMA transfer complete/error interrupts  */
    LL_DMA_EnableIT_TC(DMA1, DMA_CH);
    LL_DMA_EnableIT_TE(DMA1, DMA_CH);

    NVIC_SetPriority(DMA_IRQn, 1);
    NVIC_EnableIRQ(DMA_IRQn);

    NVIC_SetPriority(IRQn, 1);
    NVIC_EnableIRQ(IRQn);
}

static cb_t doneH;

void dspi_tx(const void *data, uint32_t numbytes, cb_t doneHandler) {
    // DMESG("dspi tx");

    if (doneH)
        panic();
    doneH = doneHandler;

    /* Reset the threshold bit */
    CLEAR_BIT(SPIx->CR2, SPI_CR2_LDMATX | SPI_CR2_LDMARX);

    LL_DMA_ConfigAddresses(DMA1, DMA_CH, (uint32_t)data, (uint32_t) & (SPIx->DR),
                           LL_DMA_DIRECTION_MEMORY_TO_PERIPH);
    LL_DMA_SetDataLength(DMA1, DMA_CH, numbytes);

    LL_SPI_EnableDMAReq_TX(SPIx);
    LL_SPI_Enable(SPIx);
    LL_DMA_EnableChannel(DMA1, DMA_CH);
}

// this is only enabled for error events
void IRQHandler(void) {
    DMESG("SPI handler!");
}

/*void DMA_Handler(void) {
    // uint32_t isr = DMA1->ISR;

    DMA_ClearFlag(DMA1);
    LL_DMA_DisableChannel(DMA1, DMA_CH);

    // DMESG("DMA irq %x", isr);

    while (LL_SPI_GetTxFIFOLevel(SPIx))
        ;
    while (LL_SPI_IsActiveFlag_BSY(SPIx))
        ;

    // DMESG("DMA spi done waiting");

    cb_t f = doneH;
    if (f) {
        doneH = NULL;
        f();
    }
}*/

#endif // SPI2

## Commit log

2021-02-09 v1.1 Pi Smart shield config
    Changelog-
    -Updated SPI support for Rpi comms from stm board .
    [ARMv8MBLl_config.txt, ARMv8MMLl_config.txt, ARMv8MMLld_config.txt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]
2021-02-09 v1.1.1 Updated RPi SPI
    -Changelog
    -Updated SPI communication on Pi- rewritten receiving response on MISO pin. Read on return of xfer3.
2021-02-22 v1.2 Updated RPi SPI
    -Updated Raspberry pi SPI to reliably read STM32F0 spi data
    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
2021-02-23 v1.2.2 Updated RPi Arcade
    - Now using Pygame a window is created, fetching pixel information from a SPI transfer to update on a window pixel by pixel
    -SPI now initiates a transfer through class method call
    -Revamped Rpi handler in smart shield framework
    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
2021-03-09 v1.3.0 Merged Makecode, Updated Rpi hookers
    -Merged makecode arcade v1.14.13 for audio output
    -Updated RPI hooker for display output
    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
    [ArcadeRpiSmartShield 33 MCU.SchDoc, ArcadeRpiSmartShield 33 Pi interface.SchDoc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]
2021-03-15 v1.3.1 Updated RPi comms
    Changelog
    -Updated Rpi TX & RX methods using SPI & DMA CH 4/5
    [ArcadeRpiSmartShield 33 MCU.SchDoc, ArcadeRpiSmartShield 33 Pi interface.SchDoc]
2021-03-16 v1.3.2 RPi comms Bug Fix
    -Fixed Rpi comms- enabled Sys clocks, added while loop to keep device alive.
    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
    [main.c]
